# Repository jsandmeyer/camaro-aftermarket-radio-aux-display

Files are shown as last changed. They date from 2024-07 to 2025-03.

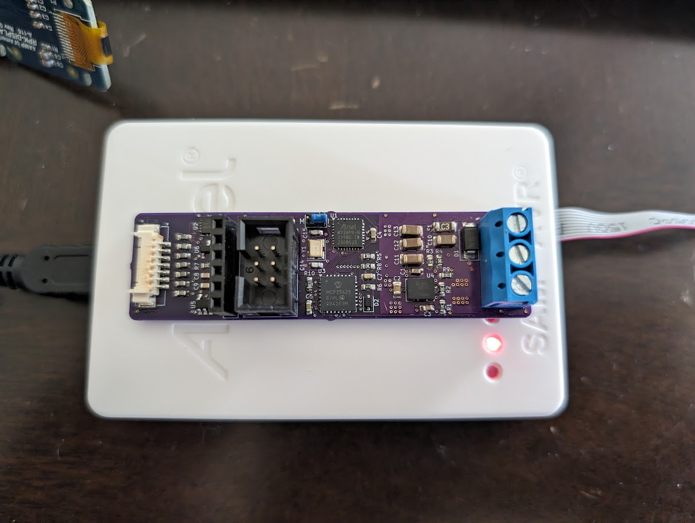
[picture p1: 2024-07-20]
pictures/V3/V3 Soldered and Programmed.jpg

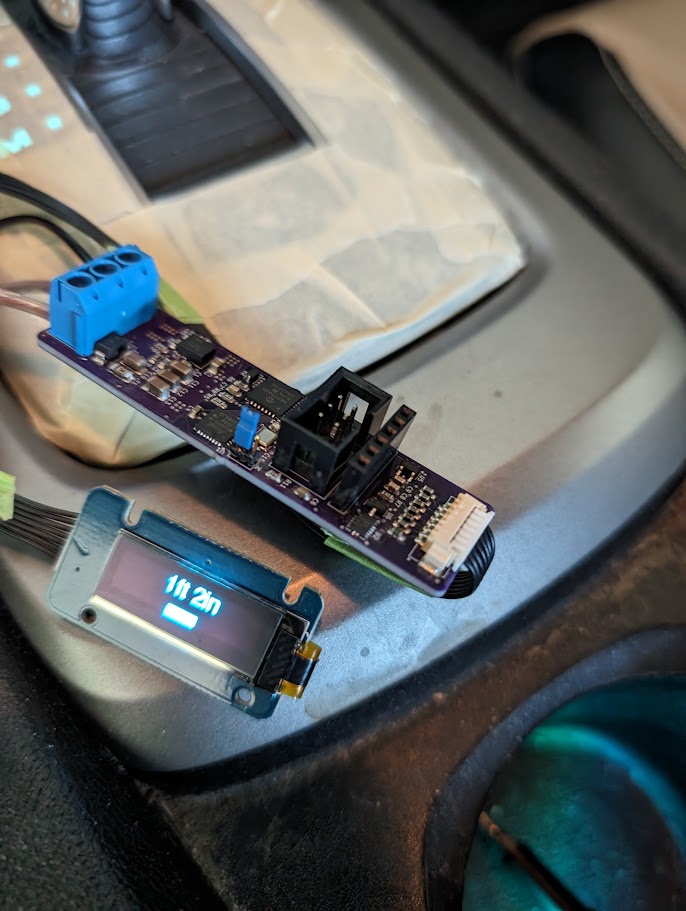
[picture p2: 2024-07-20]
pictures/V3/V3 Reverse Sensor Display.jpg

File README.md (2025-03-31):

## Camaro Temperature & Reverse Sensor Display Shim

This provides resources to help you build something to get the temperature display of a PAC RPK5-GM4102 (or 4101) to function while using a Maestro RR instead of the box that came with the PAC kit.
This is useful if you want to have the Maestro functions to get/update vehicle data, but have the nice function and appearance of the OEM-style HVAC knobs provided by the PAC kit.

### Important
This project is not endorsed by GM, the makers of any trim kits (PAC, iDatalink) or my aftermarket radio, any forum or their users, or anyone else, including any entities named in this repository.
It is a personal project which I have completed, and I have taken a substantial risk to my own property by building and installing this project.

This project (except for PCB footprints supplied by KiCad's included files) is licensed under the MIT license.
Please read the attached LICENSE document.
All code was written by myself, based on documentation provided by libraries or electronic part providers.
All PCB design (except for some footprints) was completed by myself.

### Background

[This forum post on camaro5.com](https://www.camaro5.com/forums/showthread.php?t=588249) goes over the process of combining the two dash kit elements.
Note the OP and others never got the temperature display to work.
This is because the PAC trim component's harness does not have CANBUS access, and the PAC controller was relaying the temperature (and possibly other data) over the Serial line running between the radio and HVAC harnesses.

### Goal

My goal was simply to display the temperature on the OLED.
In the process of design, I also decied to have it show backup sensor data.
The original MyLink radio showed a triangle with an exclamation point in one of five positions over the backup camera when reversing, and it would change color and flash depending on distance.
I wanted to display something similar on the OLED when reversing, because no aftermarket radios seem to support showing the backup sensor data AND camera view at the same time!
The latest version of this module is also able to determine whether the car is displaying metric or imperial units, so there is no need to adjust the jumper on the PCB.

### Reverse Engineering the Hardware

I was able to do some reverse engineering of the PAC RPK5, but without a logic analyzer or serial reading device, I could not do so completely.
I did determine that if I depinned the PAC harness to include only power input, net 5060 low-speed GMLAN, and net 7458 serial data, it would power on and the temperature would display.
However, if I disconnected the TX pin on the PAC controller's internal CANBUS modem (as suggested by its documentation, would force it into "read-only" mode) it would fail completely.
I also discovered that the OLED board used by PAC is a very standard SSD1306 SPI model, and it's roughly equivalent to something you could buy off a hobby site - and the cable connector is also a standard Molex PicoBlade (though the included cable is a crossover cable, likely not made by Molex).

### Reverse Engineering the CANBUS

#### Hardware and Software

I used an Arduino Uno and the [Sparkfun CANBUS shield](https://www.sparkfun.com/products/13262) to prove viability.
With this setup, I was able to snoop on my car's low-speed CANBUS (net 5060) via the main ODB connector using pin 1 for CAN_H and pin 4 for CAN_L and GND.
Using the [mcp_can library](https://github.com/coryjfowler/MCP_CAN_lib) I was able to read temperature and other data.
Eventually, some light googling got me [some details](https://docs.google.com/spreadsheets/d/1pFdixF6W0XK4SR6pXHIlZaFRo9qM5XmAWOK7JcAQdDM/) regarding CANBUS IDs for this car and for other GM cars.

My configuration for this was to:
* Call `CAN0.begin(MCP_STDEXT, CAN_33K3BPS, MCPHZ)` to initialize low-speed CANBUS at 33.3k.
* To configure the filters, I used online resources to try to determine what different ARB IDs meant, and in some cases, even turned off filtering and simply looked through the stream for messages.
* Call `CAN0.setMode(MCP_LISTENONLY)` for read-only CANBUS operation

#### Hardware V2

After confirming this configuration, I switched to using a bare ATMEGA328P chip (similar to the VQFN package I would use in production) and a MCP25625 CAN controller with transciever.
I added ferrite beads to the OLED connector after seeing that PAC decided to use them in their controller board.
I also added a switch to allow selection of Metric vs Imperial units.

#### Hardware V3

This is the first production version.
I added a nice TI power supply designed via Webench, soldered everything down, and also used a jumper to select Metric vs Imperail units (in place of the switch).
Some SMT components are slightly different, like using an AMEGA328PB instead of the ATMEGA328P, or the different footprint of the oscillator.

#### Hardware V6

This is the second production version.
Versions 4 and 5 had issues which prevented them from going to production.
This version includes mounting holes, extra power supply filtering, a watchdog to reboot the MCU if there are too many errors during boot, and auto-sensing of temperature/distance units instead of using a jumper.
The circuit also uses the 3.3V power supply for all logic except for the CAN transciever, which runs on the base 5V.

#### Logs

Temperature was easy.

For my 2014 Camaro, it comes in as 0x10424060 without mask, or 0x212 with the mask.
The second byte `buf[1]` contains the temperature... kind-of.
You have to divide the hex value by two, and subtract 40, to get degrees in celsius.

The backup sensors took more work.

I found that they were streaming data on 0x103A80BB without mask, or 0x1D4 with the mask.

The *second nibble* of the first byte `buf[0] & 0x0F` indicates the park-assist staus.
A value of `0` indicates park-assist is ON, and a value of `F` indicates it is OFF.
The *first nibble* `buf[0] & 0xF0` seems related to something else, and also seemed to vary.

The Bosch parking assist unit seems to report the direction and distance to the *closest* object only.
The second byte `buf[1]` contains the distance, in cm, from 0-255cm.

The position is more complicated.
The Bosch unit has four sensors, but reports three positional channels: Middle, Right, and Left.
It may report a single positional channel, or two adjacent channels, to form five possible locations to render the warning triangle!
The position comes out in bytes 3-4 `buf[2-3]`, split into nibbles indicating positions `[M, R], [N/A, L]`.
A value of 0 indicates the channel is off, but values of 1 thorugh 5 indicate the relative "closeness" and beep/flash speed, with 1 being closest and 5 being furthest.
If two channels are activated, such as to indicate a middle-left obstruction, both channels would have the same value.
I also decided it would be prudent to have a timeout to turn off park-assist display if no data was received, in case the MCU missed the "off" signal.

Lastly, I decided to use data from ARB ID 0x425 to decide whether to use Imperial or Metric units.
The vehicle sends this data multiple times upon startup, so devices using only ACC power (like this) can receive it.

### Assembly

**WARNING: DO THIS ALL AT YOUR OWN RISK.  YOU MAY DAMAGE YOUR CAR OR OTHER EQUIPMENT.  MY DESIGNS PROBABLY HAVE FLAWS; I AM A WEB SOFTWARE ENGINEER AFTER ALL.**

The minimum for this to work is that you need the entire PAC kit, a Maestro RR and its standard cables, and a harness to connect the Maestro RR to the camaro.
For the main harness, you can use the one that comes with the complete iDatalink kit, or just the HRN-HRR-GM2 if you want to re-pin the harness (mandatory).

If you use the harness with the iDatalink trim kit, just leave the HVAC connector and trim connector hanging.
For the cheap option, I originally removed pins 2, 13, 20, and 23 from the HRN-HRR-GM2 to make it seem to work.
If you are particularly clever, you might be able to figure out how to wire in the car's microphone to the harness, like the PAC kit does, and connect it to a 3.5mm jack for the radio.
However, for my final build, I did use the harness included in the KIT-CAM1 with the HVAC control disconnected.

I spliced into the 5060 Low-Speed GMLAN cable, the GND line, and the red "accessory power" line between the Maestro RR unit and my aftermarket radio to power the circuit board.

I used a non-crossover Molex Picoblade cable to connect the circuit board to the OLED display.
I had to temporarily remove a retaining clip from the RPK5 trim to install the cable.
I believe the cable included in the RPK5 is a crossover cable, **please do not use the included display cable for this project**.

See my analysis of the various harness connector configurations in the `2014 camaro connectors.xlsx` file in this repository.

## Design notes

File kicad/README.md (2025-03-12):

### PCB files

PCB construction:

* 4-layer PCB with 5mil trace width and spacing, 10mil drill / 20mil via
* Contact finish must be ENIG due to fine-pitch components
* Use a stencil with solder paste and a hot plate or reflow oven for best results

Installation notes:

* Splice ACC power from the controller-to-radio harness (typically red wire), not direct battery (typically yellow wire).  Otherwise, your battery will drain.
* Splice low-speed GMLAN (green/white) and GND (black) from the main harness.
* Use a NEW 7-pin Molex PicoBlade cable (F-F) to connect.  DO NOT use the crossover cable that came with the trim unless you intend to re-pin the cable.  Wrap the cable in harness tape.
* You will have to remove one of the retention clips on the trim temporarily to replace the cable.
* The new circuit board should be installed in the cavity that the HVAC wires come through, below the radio.

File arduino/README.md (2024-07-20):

### Arduino Sketch

Compiled sketch size is about 28kb.

External libraries needed:

* mcp_can by coryjfowler v1.5.1
* Adafruit GFX Library 1.11.9
* Adafruit SSD1306 2.5.9

Install board variant from this link to %LocalAppData%/Arduino15/packages/arduino/hardware/avr/1.8.6/variants/pb-variant
https://github.com/MCUdude/MiniCore/blob/master/avr/variants/pb-variant/pins_arduino.h

Create a copy of the "uno" board in your boards.txt with a new designator and name, like uno_pb (name Arudino Uno PB mod).
Change the "variant" value of this copy to "pb-variant" to represent the new folder/file.

I programmed with ATMEL Ice, but an AVIRSP MkII should work too.
I used a standard FTDI interface for "debugging" via serial.

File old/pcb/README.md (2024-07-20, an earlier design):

### PCB files

PCB construction:

* 4-layer PCB with 5mil trace width and spacing support, and standard drill limits
* Contact finish must be ENIG fdue to fine-pitch components
* Use a stencil with solder paste and a reflow oven or hot plate for best results, especially due to QFN packages

V3: original design, no mounting holes and no EMI filter.  Boots up about 98% of the time.

V5: new design, but still in progress and untested.  Change notes:

* Added EMI filter based on webench design
* Added mounting holes
* 3.3V power supply replaced with model with more features
* 3.3V power supply will wait for 5V PGOOD signal
* OLED RESET controller removed; reset pin now feeds from MCU
* Level shifter is repalced with a device with more pins
* Level shifter is disabled until 3.3V PGOOD signal

Installation notes:

* Splice ACC power from the brain-to-radio harness (typically red wire), not direct battery (typically yellow wire).  Otherwise, your battery will drain.
* Splice low-speed GMLAN (green/white) and GND (black) from the main harness.
* Use a long, standard Molex PicoBlade cable (F-F) to connect.  Do not use the crossover cable that came with the trim.  Wrap the cable in harness tape.
* You will have to remove one of the tabs on the trim temporarily to replace the cable.
* The new circuit board should be installed in the cavity that the HVAC wires come through, below the radio.

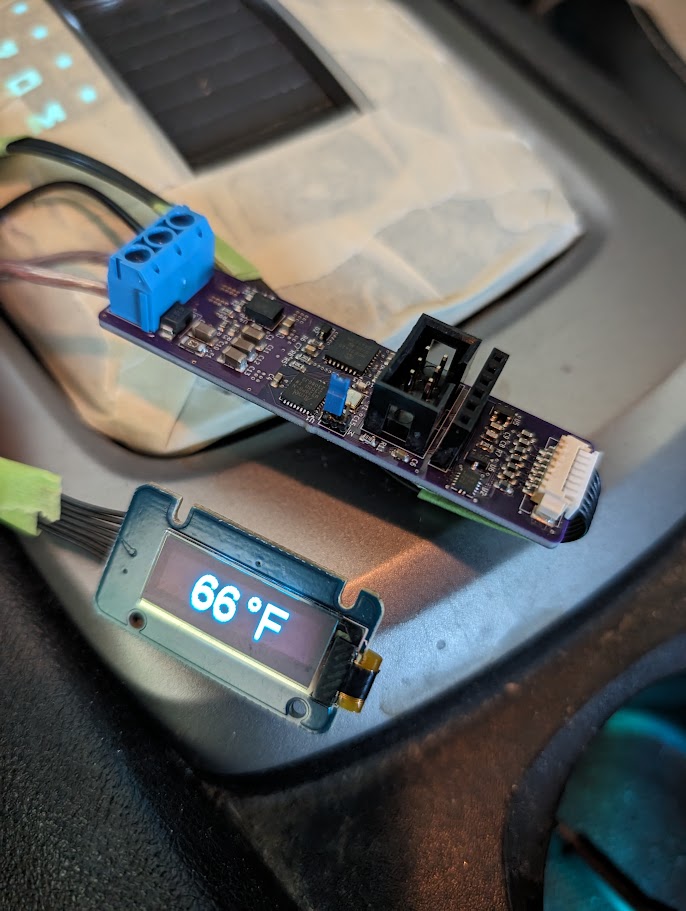
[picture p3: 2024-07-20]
pictures/V3/V3 Temperature Display.jpg

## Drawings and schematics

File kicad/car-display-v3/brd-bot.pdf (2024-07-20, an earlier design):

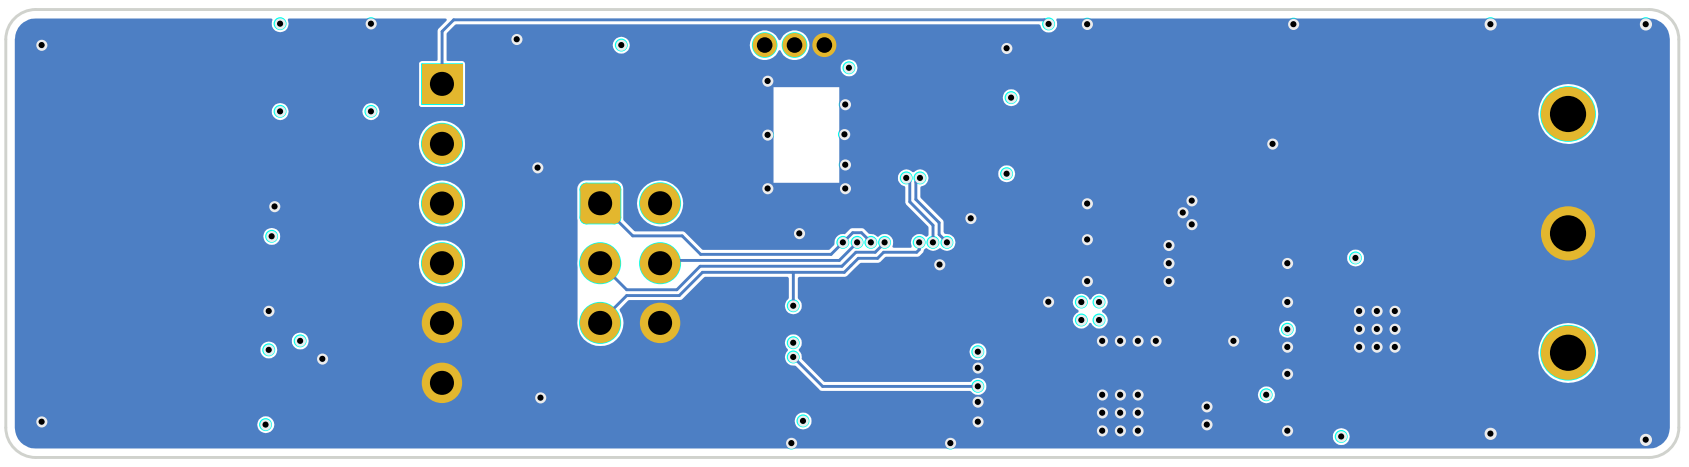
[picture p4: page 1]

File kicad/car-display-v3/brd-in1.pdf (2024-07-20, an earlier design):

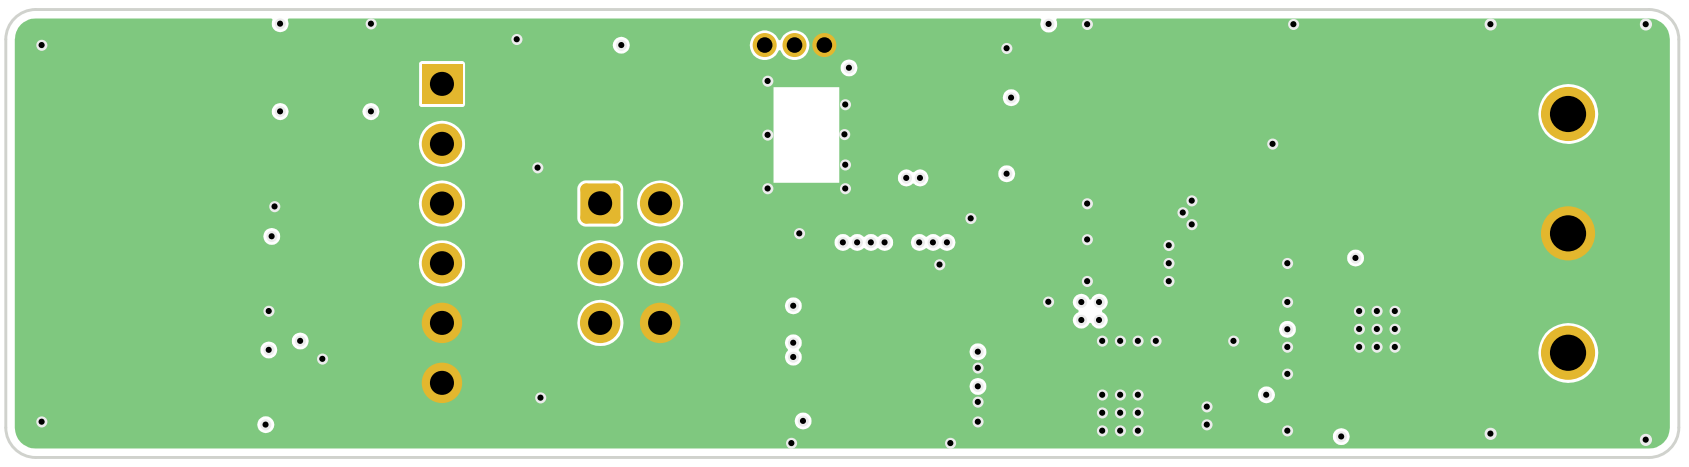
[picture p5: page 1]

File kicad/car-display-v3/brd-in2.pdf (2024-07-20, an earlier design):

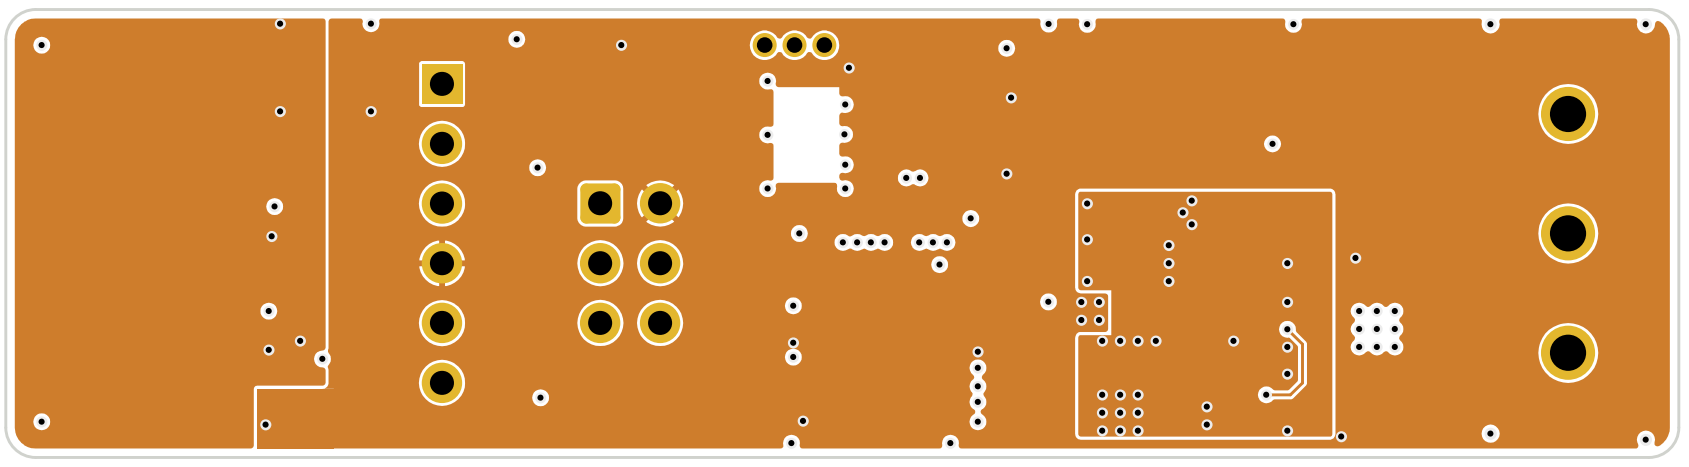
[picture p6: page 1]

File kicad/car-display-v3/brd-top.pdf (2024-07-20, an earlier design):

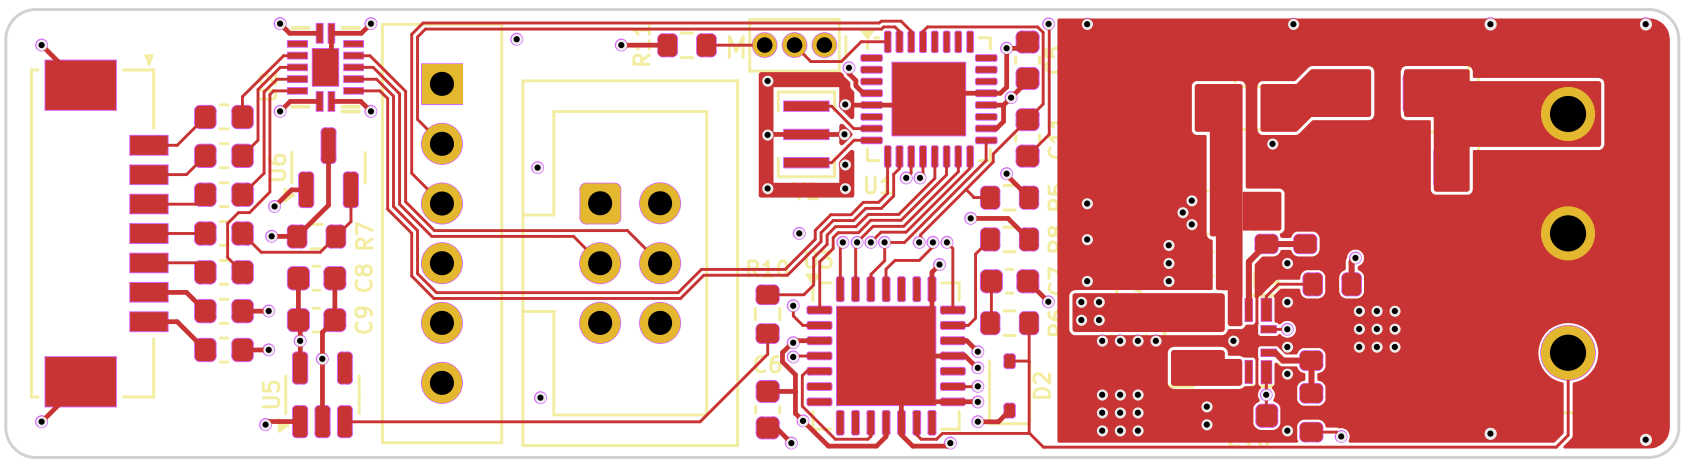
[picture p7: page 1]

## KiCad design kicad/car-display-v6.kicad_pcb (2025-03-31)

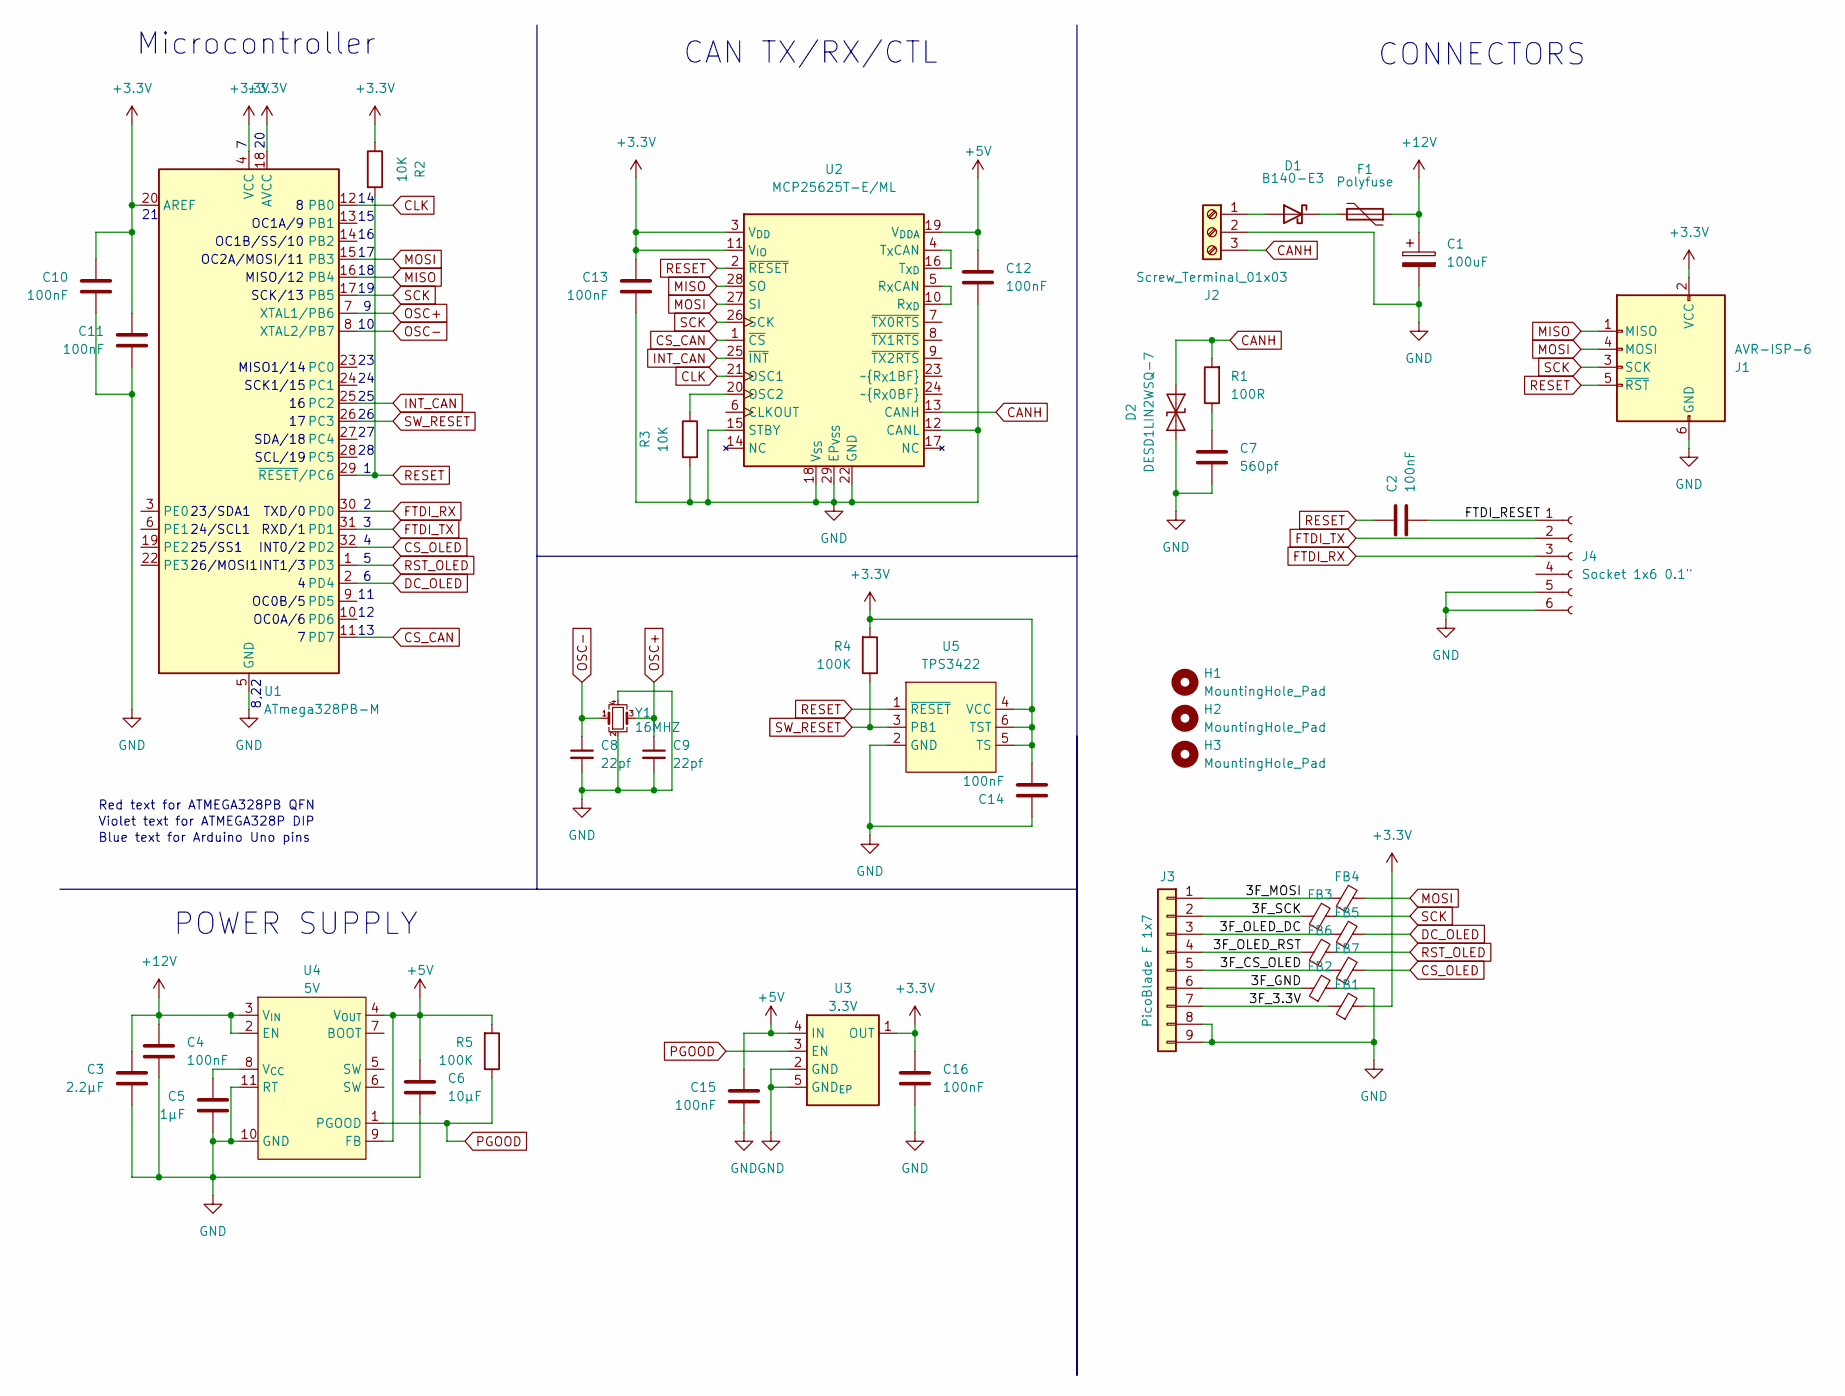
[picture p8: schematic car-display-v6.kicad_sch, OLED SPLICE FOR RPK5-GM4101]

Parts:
C1: 100uF; CP_Elec_6.3x7.7
C2, C4, C10, C11, C12, C13, C14, C15, C16: 100nF; C_0402_1005Metric
C3: 2.2µF; C_0805_2012Metric
C5: 1µF; C_0603_1608Metric
C6: 10µF; C_0805_2012Metric
C7: 560pf; C_0603_1608Metric
C8, C9: 22pf; C_0402_1005Metric
D1: B140-E3; D_SMA
D2: DESD1LIN2WSQ-7; D_SOD-323
F1: Polyfuse; Fuse_1206_3216Metric
FB1, FB2, FB3, FB4, FB5, FB6, FB7: 120X; L_0402_1005Metric
H1, H2, H3: MountingHole_Pad; MountingHole_2.2mm_M2_DIN965
J1: AVR-ISP-6; PinHeader_ISP_POGO
J2: Screw_Terminal_01x03; TerminalBlock_3P
J3: PicoBlade F 1x7; CON_532610771_MOD
J4: Socket 1x6 0.1"; PinSocket_1x06_P2.54mm_Vertical_Box
R1: 100R; R_0603_1608Metric
R2, R3: 10K; R_0402_1005Metric
R4, R5: 100K; R_0402_1005Metric
U1: ATmega328PB-M; QFN-32-1EP_5x5mm_P0.5mm_EP3.1x3.1mm
U2: MCP25625T-E/ML; QFN-28-1EP_6x6mm_P0.65mm_EP4.25x4.25mm
U3: 3.3V; Texas_X2SON-4_1x1mm_P0.65mm_MOD
U4: 5V; QFN-FCMOD_TI_11B
U5: TPS3422; Texas_USON-6_1x1.45mm_P0.5mm_SMD
Y1: 16MHZ; Crystal_SMD_3225-4Pin_3.2x2.5mm

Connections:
+3.3V: C10.1, C11.1, C13.1, C14.2, C16.1, FB1.2, J1.2 (VCC), R2.1, R4.2, U1.4 (VCC), U1.18 (AVCC), U1.20 (AREF), U2.3 (V_{DD}), U2.11 (V_{IO}), U3.1 (OUT), U5.4 (VCC), U5.5 (TS), U5.6 (TST)
+5V: C6.1, C12.1, C15.1, R5.2, U2.19 (V_{DDA}), U3.4 (IN), U4.4 (V_{OUT}), U4.9 (FB)
+12V: C1.1, C3.1, C4.1, F1.1, U4.2 (EN), U4.3 (V_{IN})
/3F_3.3V: FB1.1, J3.7
/3F_CS_OLED: FB7.1, J3.5
/3F_GND: FB2.1, J3.6
/3F_MOSI: FB4.1, J3.1
/3F_OLED_DC: FB5.1, J3.3
/3F_OLED_RST: FB6.1, J3.4
/3F_SCK: FB3.1, J3.2
/FTDI_RESET: C2.2, J4.1
CANH: D2.2 (A2), J2.3, R1.2, U2.13 (CANH)
CLK: U1.12 (PB0), U2.21 (OSC1)
CS_CAN: U1.11 (PD7), U2.1 (~CS)
CS_OLED: FB7.2, U1.32 (PD2)
DC_OLED: FB5.2, U1.2 (PD4)
FTDI_RX: J4.3, U1.30 (PD0)
FTDI_TX: J4.2, U1.31 (PD1)
GND: C1.2, C3.2, C4.2, C5.2, C6.2, C7.2, C8.2, C9.2, C10.2, C11.2, C12.2, C13.2, C14.1, C15.2, C16.2, D2.1 (A1), FB2.2, J1.6 (GND), J2.2, J3.8, J3.9, J4.5, J4.6, R3.2, U1.5 (GND), U1.21 (GND), U1.33 (GND), U2.12 (CANL), U2.15 (STBY), U2.18 (V_{SS}), U2.22 (GND), U2.29 (EP_{VSS}), U3.2 (GND), U3.5 (GND_{EP}), U4.10 (GND), U4.11 (RT), U5.2 (GND), Y1.2, Y1.4
INT_CAN: U1.25 (PC2), U2.25 (~INT)
MISO: J1.1 (MISO), U1.16 (PB4), U2.28 (SO)
MOSI: FB4.2, J1.4 (MOSI), U1.15 (PB3), U2.27 (SI)
unnamed: C7.1, R1.1
unnamed: D1.2 (A), J2.1
unnamed: D1.1 (K), F1.2
unnamed: R3.1, U2.20 (OSC2)
unnamed: U2.5 (R_{X}CAN), U2.10 (R_{XD})
unnamed: U2.4 (T_{X}CAN), U2.16 (T_{XD})
unnamed: C5.1, U4.8 (V_{CC})
OSC+: C9.1, U1.7 (XTAL1/PB6), Y1.3
OSC-: C8.1, U1.8 (XTAL2/PB7), Y1.1
PGOOD: R5.1, U3.3 (EN), U4.1 (PGOOD)
RESET: C2.1, J1.5 (~RST), R2.2, U1.29 (~RESET/PC6), U2.2 (~RESET), U5.1 (~RESET)
RST_OLED: FB6.2, U1.1 (PD3)
SCK: FB3.2, J1.3 (SCK), U1.17 (PB5), U2.26 (SCK)
SW_RESET: R4.1, U1.26 (PC3), U5.3 (PB1)

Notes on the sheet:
23/SDA1
OC0B/5
INT1/3
RXD/1
INT0/2
Red text for ATMEGA328PB QFN
CAN TX/RX/CTL
SCK1/15
8,22
OC1B/SS/10
OC0A/6
POWER SUPPLY
Blue text for Arduino Uno pins
SCL/19
24/SCL1
SCK/13
TXD/0
SDA/18
26/MOSI1
CONNECTORS
MISO/12
OC1A/9
MISO1/14
25/SS1
OC2A/MOSI/11
Microcontroller
Violet text for ATMEGA328P DIP

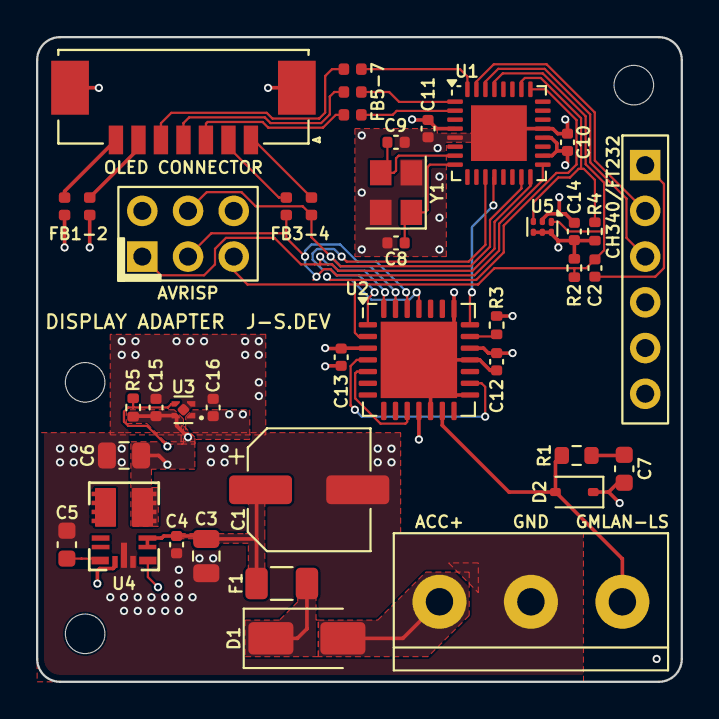
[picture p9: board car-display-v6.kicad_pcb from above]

Board: 4 copper layers, 35.8 x 35.8 mm, 44 parts (0 on the bottom side), 36 nets.

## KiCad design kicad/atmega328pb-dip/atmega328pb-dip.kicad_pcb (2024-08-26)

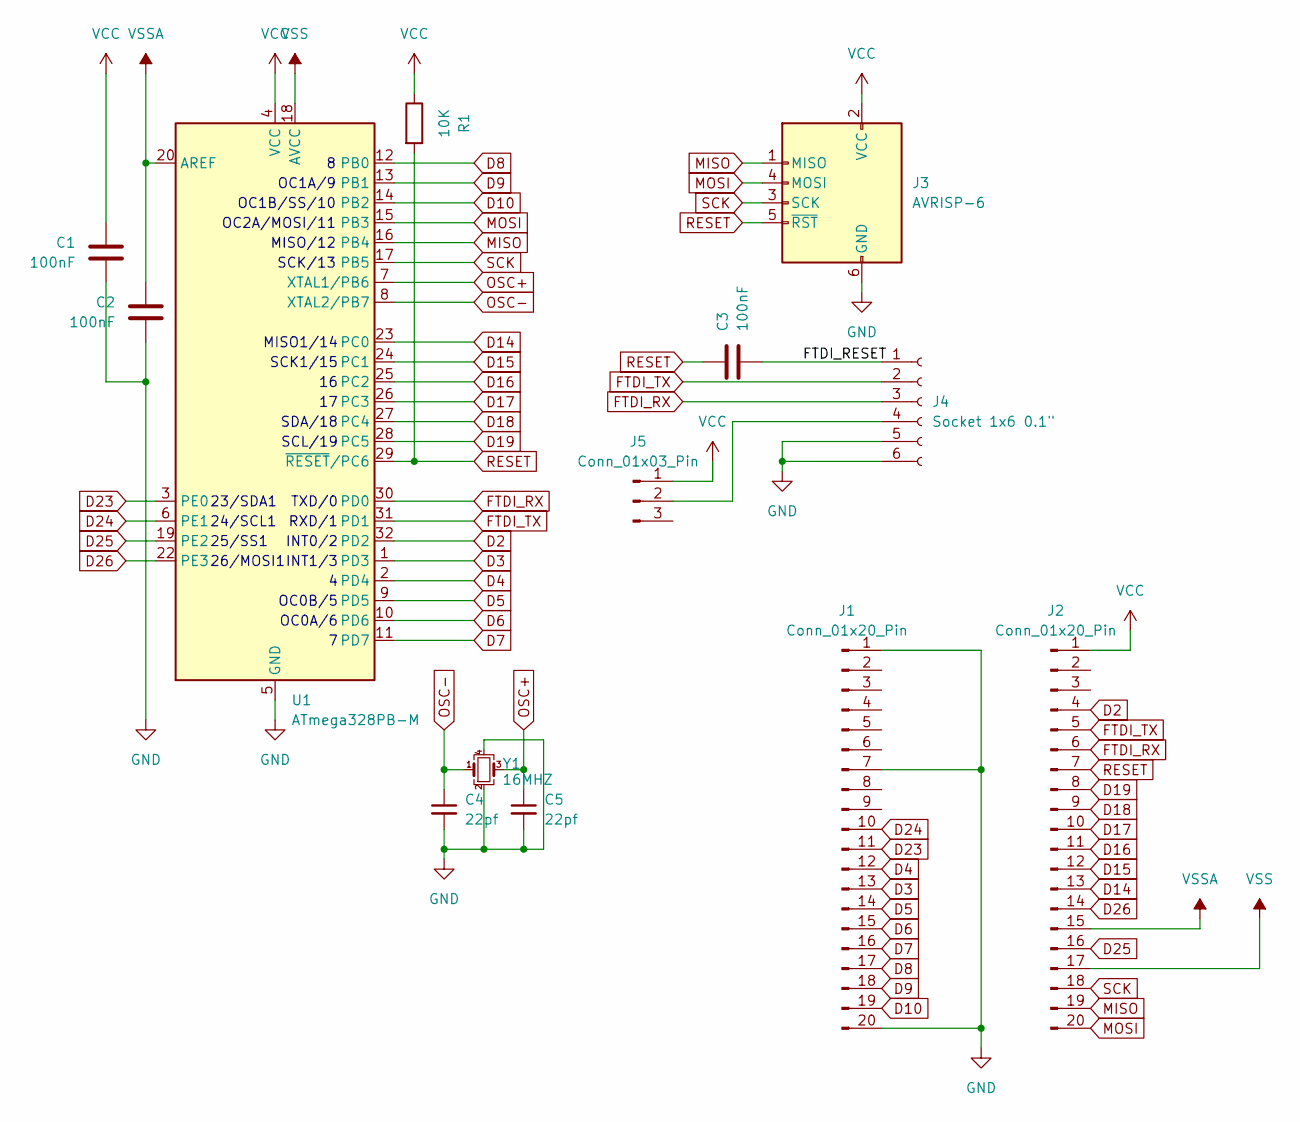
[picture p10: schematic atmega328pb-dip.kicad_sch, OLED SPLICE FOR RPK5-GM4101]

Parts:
C1, C2, C3: 100nF; C_0402_1005Metric
C4, C5: 22pf; C_0402_1005Metric
J1, J2: Conn_01x20_Pin; PinHeader_1x20_P2.54mm_Vertical
J3: AVRISP-6; PinHeader_ISP_POGO
J4: Socket 1x6 0.1"; PinSocket_1x06_P2.54mm_Vertical_Box
J5: Conn_01x03_Pin; PinHeader_1x03_P2.54mm_Vertical
R1: 10K; R_0402_1005Metric
U1: ATmega328PB-M; QFN-32-1EP_5x5mm_P0.5mm_EP3.1x3.1mm
Y1: 16MHZ; Crystal_SMD_3225-4Pin_3.2x2.5mm

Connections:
/FTDI_RESET: C3.2, J4.1
D2: J2.4, U1.32 (PD2)
D3: J1.13, U1.1 (PD3)
D4: J1.12, U1.2 (PD4)
D5: J1.14, U1.9 (PD5)
D6: J1.15, U1.10 (PD6)
D7: J1.16, U1.11 (PD7)
D8: J1.17, U1.12 (PB0)
D9: J1.18, U1.13 (PB1)
D10: J1.19, U1.14 (PB2)
D14: J2.13, U1.23 (PC0)
D15: J2.12, U1.24 (PC1)
D16: J2.11, U1.25 (PC2)
D17: J2.10, U1.26 (PC3)
D18: J2.9, U1.27 (PC4)
D19: J2.8, U1.28 (PC5)
D23: J1.11, U1.3 (PE0)
D24: J1.10, U1.6 (PE1)
D25: J2.16, U1.19 (PE2)
D26: J2.14, U1.22 (PE3)
FTDI_RX: J2.6, J4.3, U1.30 (PD0)
FTDI_TX: J2.5, J4.2, U1.31 (PD1)
GND: C1.2, C2.2, C4.2, C5.2, J1.1, J1.7, J1.20, J3.6 (GND), J4.5, J4.6, U1.5 (GND), U1.21 (GND), U1.33 (GND), Y1.2, Y1.4
MISO: J2.19, J3.1 (MISO), U1.16 (PB4)
MOSI: J2.20, J3.4 (MOSI), U1.15 (PB3)
unnamed: J4.4, J5.2
OSC+: C5.1, U1.7 (XTAL1/PB6), Y1.3
OSC-: C4.1, U1.8 (XTAL2/PB7), Y1.1
RESET: C3.1, J2.7, J3.5 (~RST), R1.2, U1.29 (~RESET/PC6)
SCK: J2.18, J3.3 (SCK), U1.17 (PB5)
VCC: C1.1, J2.1, J3.2 (VCC), J5.1, R1.1, U1.4 (VCC)
VSS: J2.17, U1.18 (AVCC)
VSSA: C2.1, J2.15, U1.20 (AREF)

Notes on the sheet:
23/SDA1
OC0B/5
INT1/3
RXD/1
INT0/2
SCK1/15
OC1B/SS/10
OC0A/6
SCL/19
24/SCL1
SCK/13
TXD/0
SDA/18
26/MOSI1
MISO/12
OC1A/9
MISO1/14
25/SS1
OC2A/MOSI/11

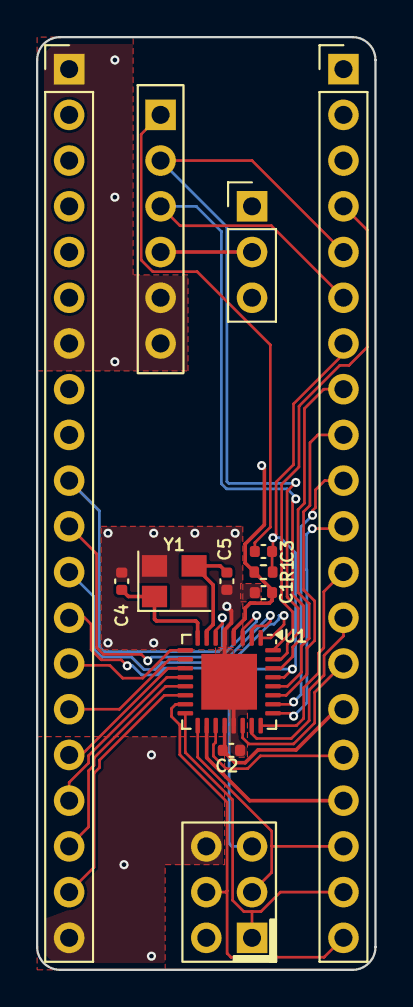
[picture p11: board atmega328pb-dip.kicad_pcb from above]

Board: 2 copper layers, 18.8 x 51.8 mm, 13 parts (0 on the bottom side), 33 nets.

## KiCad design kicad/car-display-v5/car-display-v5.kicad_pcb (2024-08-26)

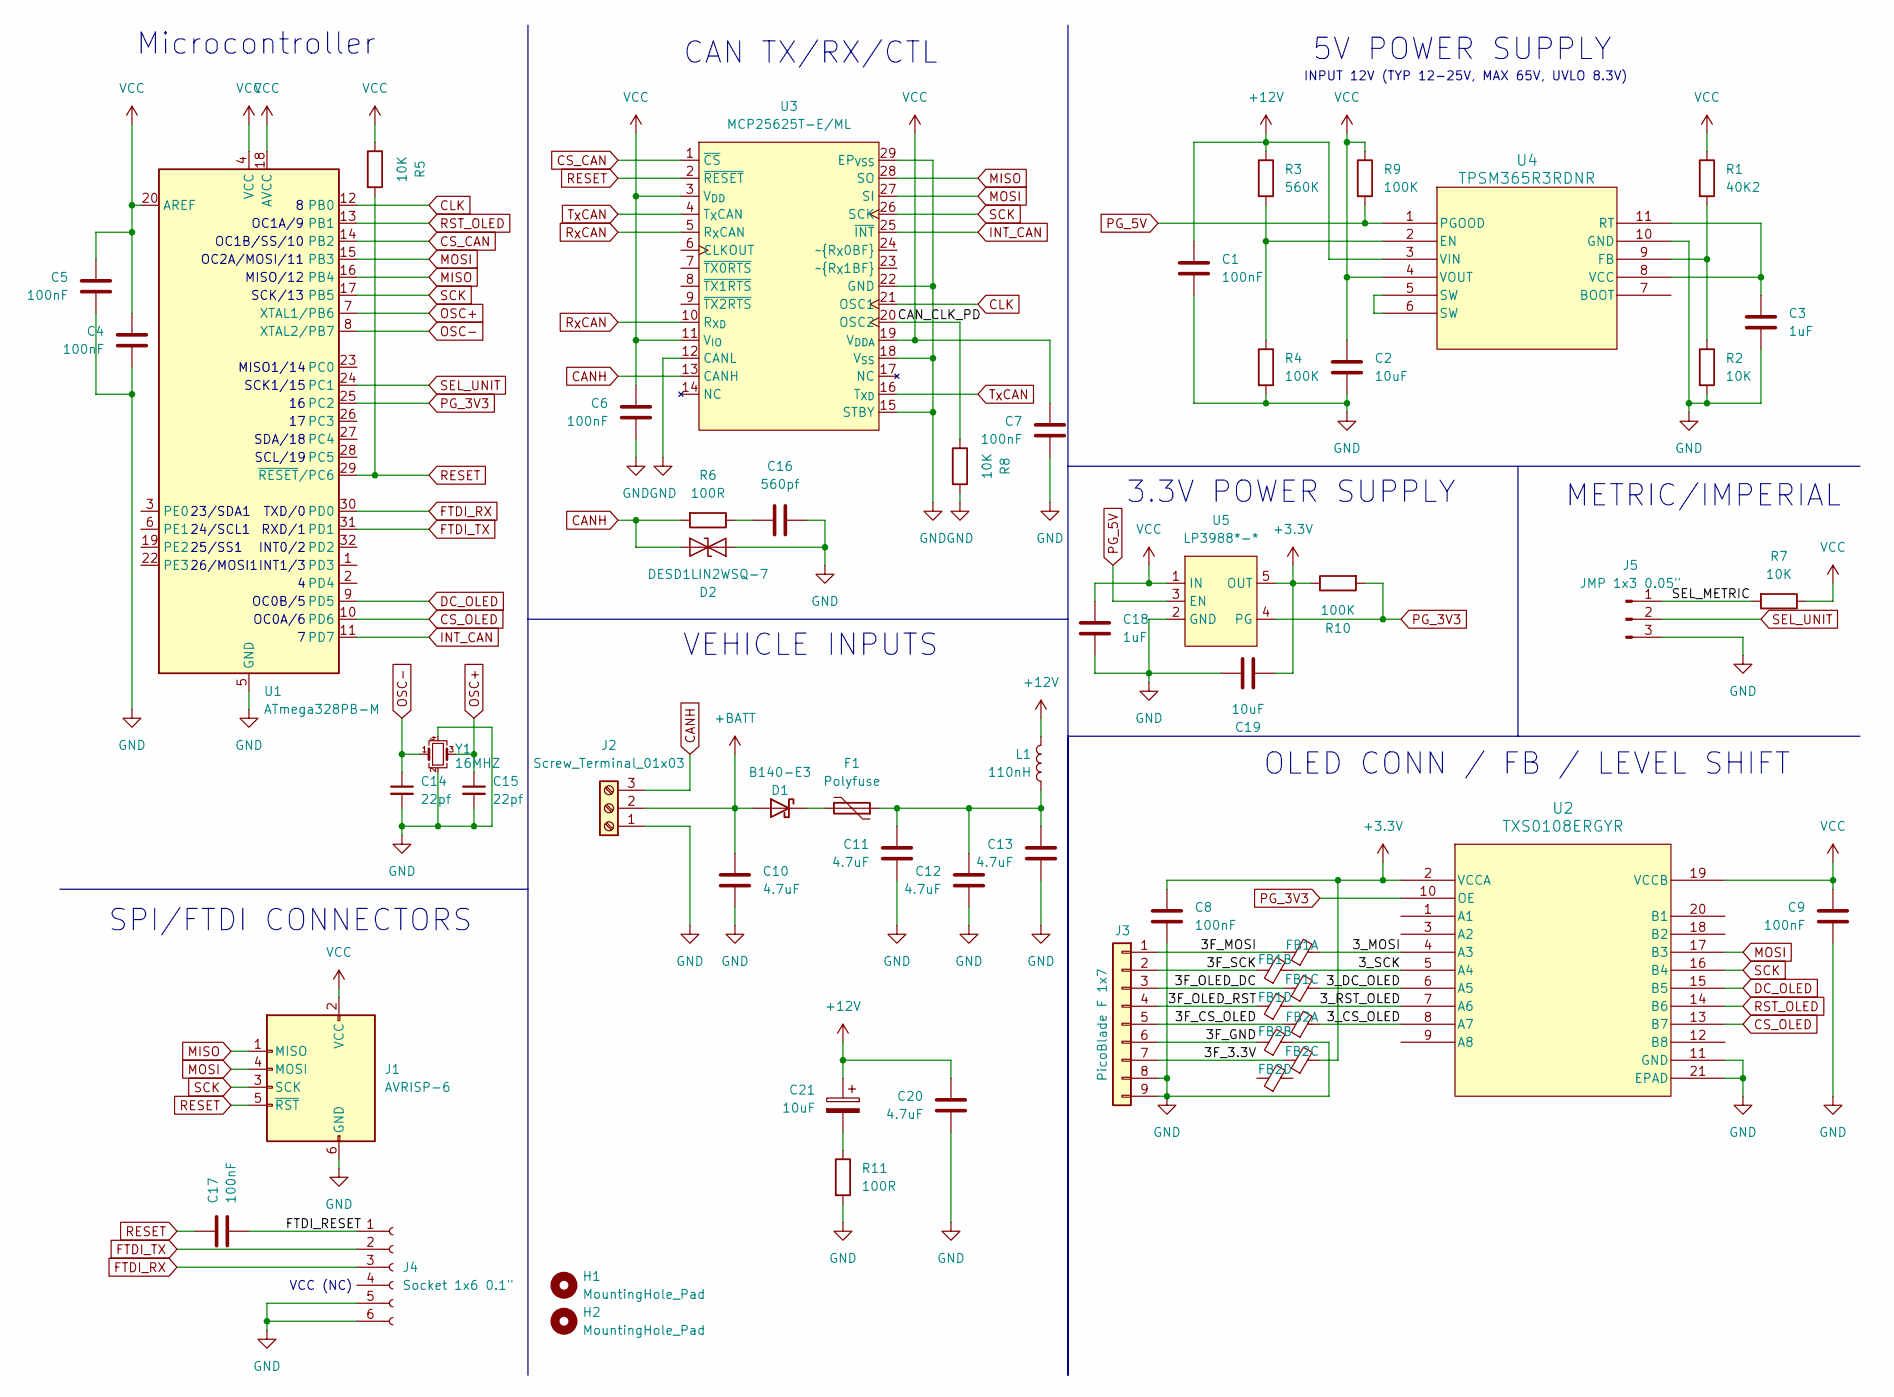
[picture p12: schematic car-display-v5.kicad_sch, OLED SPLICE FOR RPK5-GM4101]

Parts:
C1: 100nF; C_0603_1608Metric
C2: 10uF; C_0805_2012Metric
C3, C18: 1uF; C_0603_1608Metric
C4, C5, C6, C7, C8, C9, C17: 100nF; C_0402_1005Metric
C10, C11, C12, C13, C20: 4.7uF; C_1206_3216Metric
C14, C15: 22pf; C_0402_1005Metric
C16: 560pf; C_0603_1608Metric
C19: 10uF; C_0603_1608Metric
C21: 10uF; CP_Elec_5x5.9
D1: B140-E3; D_SMA
D2: DESD1LIN2WSQ-7; D_SOD-323
F1: Polyfuse; Fuse_1206_3216Metric
FB1, FB2: FerriteBead_Small_Array; fb_array_0805
H1, H2: MountingHole_Pad; MountingHole_2.2mm_M2_DIN965
J1: AVRISP-6; PinHeader_ISP_POGO
J2: Screw_Terminal_01x03; TerminalBlock_bornier-3_P5.08mm
J3: PicoBlade F 1x7; CON_532610771_MOD
J4: Socket 1x6 0.1"; PinSocket_1x06_P2.54mm_Vertical_Box
J5: JMP 1x3 0.05"; PinHeader_1x03_P1.27mm_Vertical_mod
L1: 110nH; L_0603_1608Metric
R1: 40K2; R_0402_1005Metric
R2, R5, R7, R8: 10K; R_0402_1005Metric
R3: 560K; R_0402_1005Metric
R4, R9, R10: 100K; R_0402_1005Metric
R6, R11: 100R; R_0603_1608Metric
U1: ATmega328PB-M; QFN-32-1EP_5x5mm_P0.5mm_EP3.1x3.1mm
U2: TXS0108ERGYR; RGY20_3P05X2P05
U3: MCP25625T-E/ML; QFN-28-1EP_6x6mm_P0.65mm_EP4.25x4.25mm_mod1
U4: TPSM365R3RDNR; QFN-FCMOD_365R6FRDN_TEX_M2
U5: LP3988*-*; SOT-23-5
Y1: 16MHZ; Crystal_SMD_3225-4Pin_3.2x2.5mm

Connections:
+3.3V: C8.1, C19.1, FB2.6, R10.1, U2.2 (VCCA), U5.5 (OUT)
+12V: C1.1, C20.1, C21.1, L1.1, R3.1, U4.3 (VIN)
+BATT: C10.1, D1.2 (A), J2.2
/3F_3.3V: FB2.3, J3.7
/3F_CS_OLED: FB2.1, J3.5
/3F_GND: FB2.2, J3.6
/3F_MOSI: FB1.1, J3.1
/3F_OLED_DC: FB1.3, J3.3
/3F_OLED_RST: FB1.4, J3.4
/3F_SCK: FB1.2, J3.2
/3_CS_OLED: FB2.8, U2.8 (A7)
/3_DC_OLED: FB1.6, U2.6 (A5)
/3_MOSI: FB1.8, U2.4 (A3)
/3_RST_OLED: FB1.5, U2.7 (A6)
/3_SCK: FB1.7, U2.5 (A4)
/CAN_CLK_PD: R8.1, U3.20 (OSC2)
/FTDI_RESET: C17.2, J4.1
/SEL_METRIC: J5.1, R7.2
CANH: D2.2 (A2), J2.3, R6.2, U3.13 (CANH)
CLK: U1.12 (PB0), U3.21 (OSC1)
CS_CAN: U1.14 (PB2), U3.1 (~CS)
CS_OLED: U1.10 (PD6), U2.13 (B7)
DC_OLED: U1.9 (PD5), U2.15 (B5)
FTDI_RX: J4.3, U1.30 (PD0)
FTDI_TX: J4.2, U1.31 (PD1)
GND: C1.2, C2.2, C3.2, C4.2, C5.2, C6.2, C7.2, C8.2, C9.2, C10.2, C11.2, C12.2, C13.2, C14.2, C15.2, C16.2, C18.2, C19.2, C20.2, D2.1 (A1), FB2.7, J1.6 (GND), J2.1, J3.8, J3.9, J4.5, J4.6, J5.3, R2.2, R4.2, R8.2, R11.2, U1.5 (GND), U1.21 (GND), U1.33 (GND), U2.11 (GND), U2.21 (EPAD), U3.12 (CANL), U3.15 (STBY), U3.18 (V_{SS}), U3.22 (GND), U3.29 (EP_{VSS}), U4.10 (GND), U5.2 (GND), Y1.2, Y1.4
INT_CAN: U1.11 (PD7), U3.25 (~INT)
MISO: J1.1 (MISO), U1.16 (PB4), U3.28 (SO)
MOSI: J1.4 (MOSI), U1.15 (PB3), U2.17 (B3), U3.27 (SI)
unnamed: C11.1, C12.1, C13.1, F1.1, L1.2
unnamed: C16.1, R6.1
unnamed: C21.2, R11.1
unnamed: D1.1 (K), F1.2
unnamed: R3.2, R4.1, U4.2 (EN)
unnamed: R1.2, R2.1, U4.9 (FB)
unnamed: C3.1, U4.8 (VCC), U4.11 (RT)
unnamed: U4.5 (SW), U4.6 (SW)
OSC+: C15.1, U1.7 (XTAL1/PB6), Y1.3
OSC-: C14.1, U1.8 (XTAL2/PB7), Y1.1
PG_3V3: R10.2, U1.25 (PC2), U2.10 (OE), U5.4 (PG)
PG_5V: R9.2, U4.1 (PGOOD), U5.3 (EN)
RESET: C17.1, J1.5 (~RST), R5.2, U1.29 (~RESET/PC6), U3.2 (~RESET)
RST_OLED: U1.13 (PB1), U2.14 (B6)
R_{X}CAN: U3.5 (R_{X}CAN), U3.10 (R_{XD})
SCK: J1.3 (SCK), U1.17 (PB5), U2.16 (B4), U3.26 (SCK)
SEL_UNIT: J5.2, U1.24 (PC1)
T_{X}CAN: U3.4 (T_{X}CAN), U3.16 (T_{XD})
VCC: C2.1, C4.1, C5.1, C6.1, C7.1, C9.1, C18.1, J1.2 (VCC), R1.1, R5.1, R7.1, R9.1, U1.4 (VCC), U1.18 (AVCC), U1.20 (AREF), U2.19 (VCCB), U3.3 (V_{DD}), U3.11 (V_{IO}), U3.19 (V_{DDA}), U4.4 (VOUT), U5.1 (IN)

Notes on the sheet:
23/SDA1
OC0B/5
INT1/3
RXD/1
INT0/2
3.3V POWER SUPPLY
CAN TX/RX/CTL
VEHICLE INPUTS
SCK1/15
OC1B/SS/10
OC0A/6
VCC (NC)
5V POWER SUPPLY
INPUT 12V (TYP 12-25V, MAX 65V, UVLO 8.3V)
SCL/19
24/SCL1
SCK/13
TXD/0
SDA/18
26/MOSI1
SPI/FTDI CONNECTORS
MISO/12
OC1A/9
MISO1/14
25/SS1
OC2A/MOSI/11
OLED CONN / FB / LEVEL SHIFT
Microcontroller
METRIC/IMPERIAL

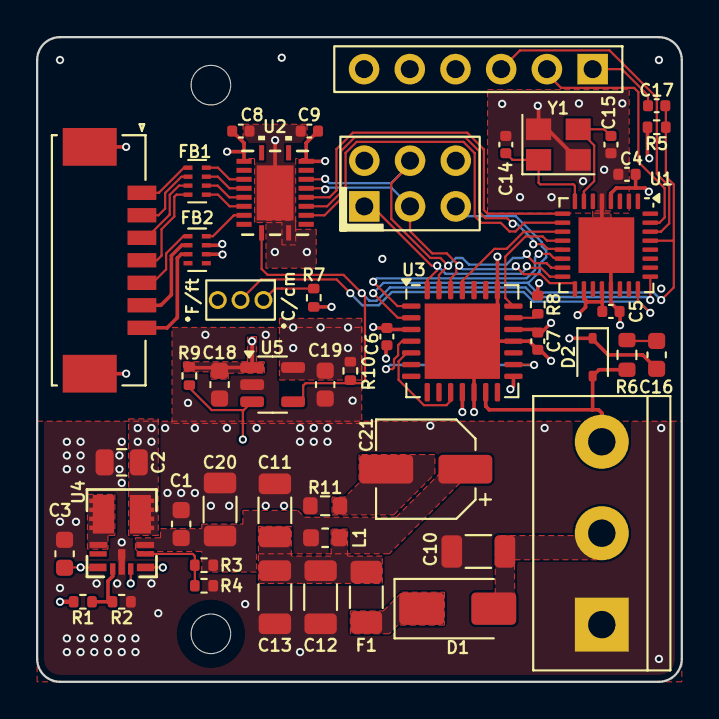
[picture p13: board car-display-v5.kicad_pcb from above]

Board: 4 copper layers, 35.8 x 35.8 mm, 51 parts (0 on the bottom side), 48 nets.

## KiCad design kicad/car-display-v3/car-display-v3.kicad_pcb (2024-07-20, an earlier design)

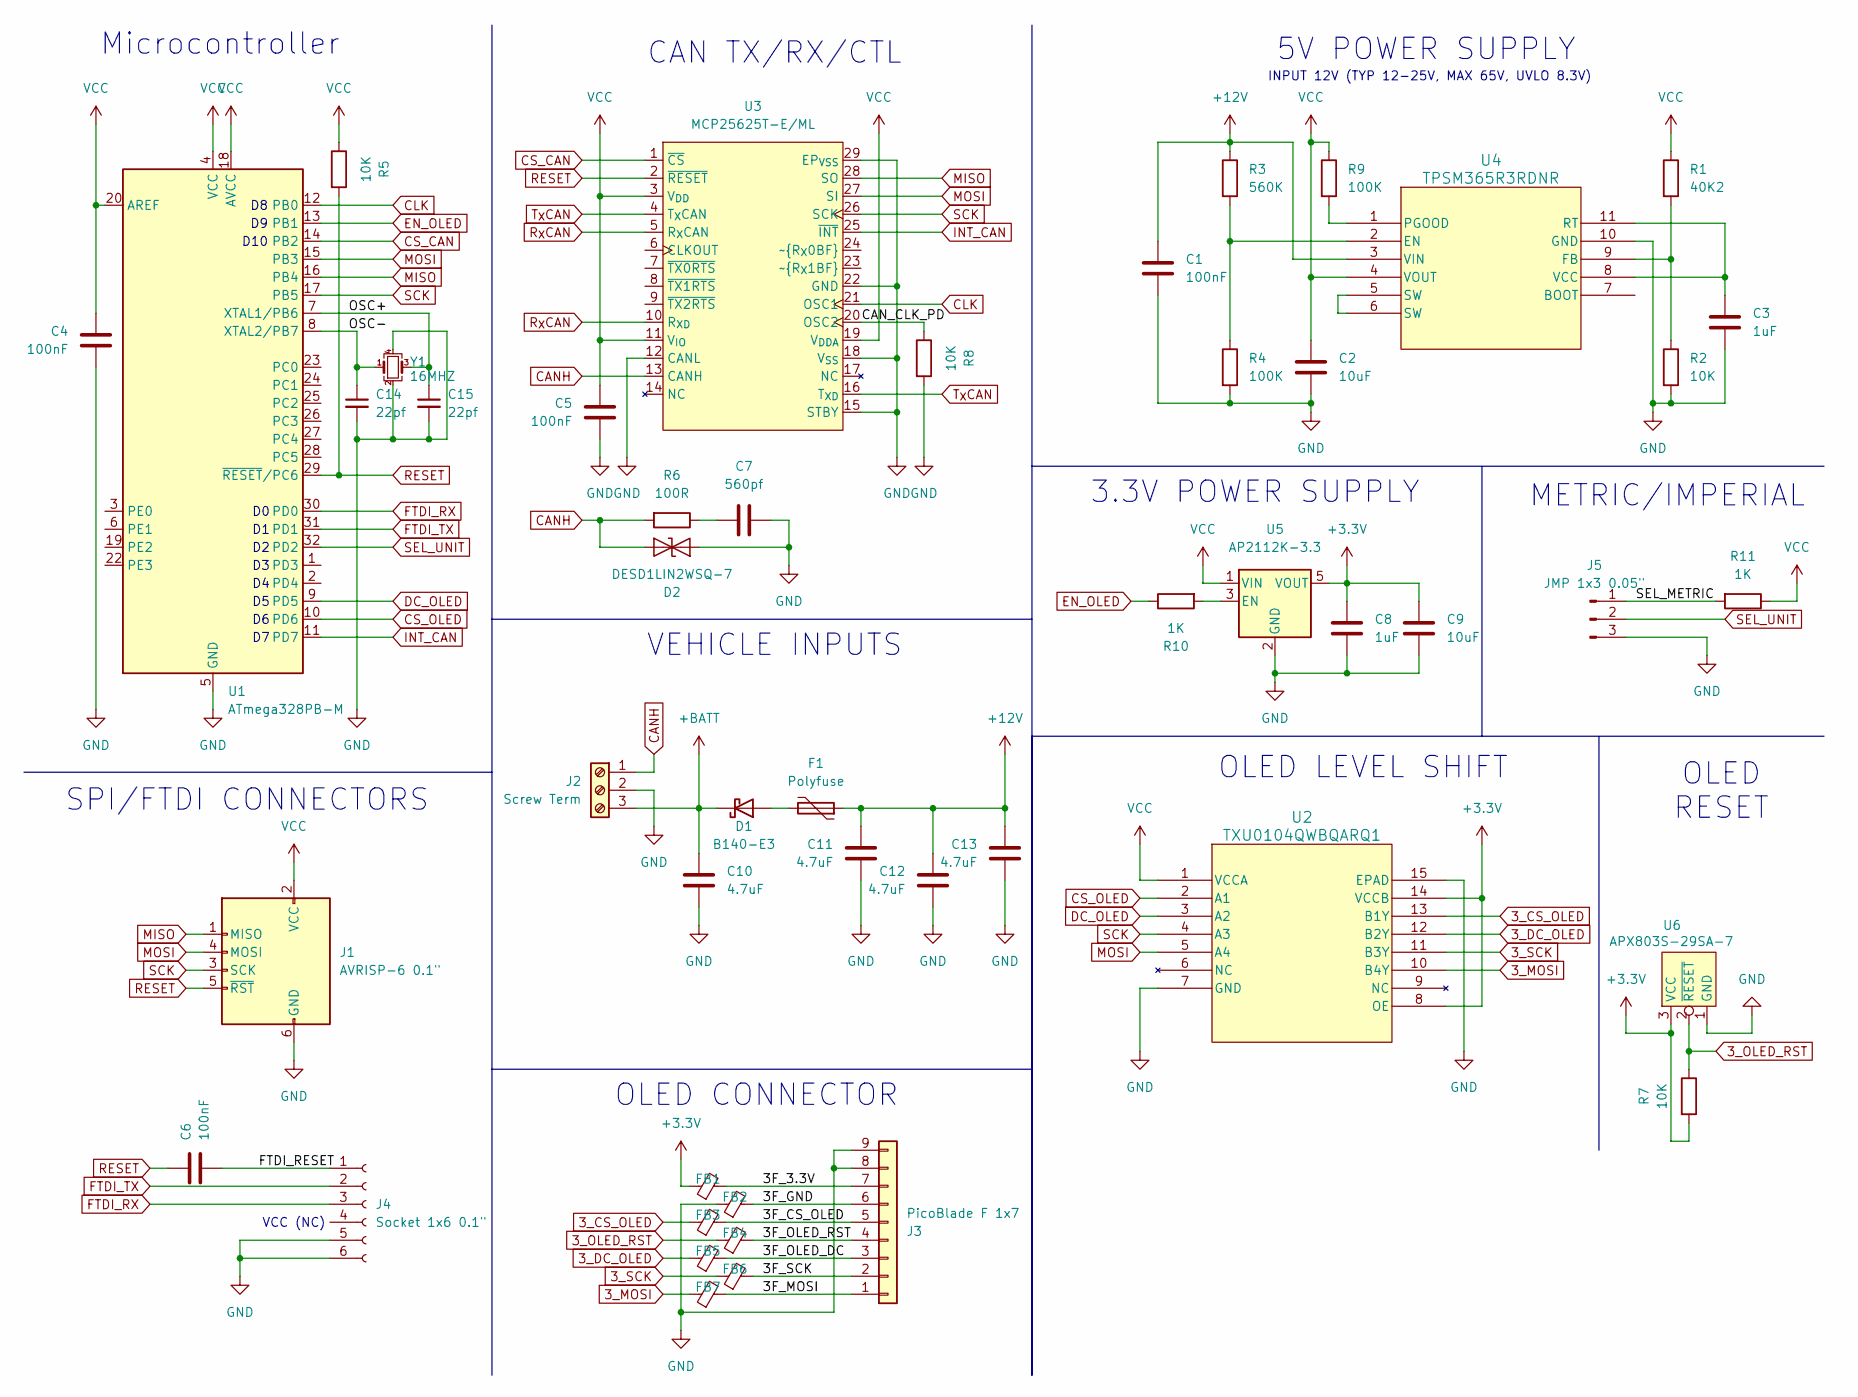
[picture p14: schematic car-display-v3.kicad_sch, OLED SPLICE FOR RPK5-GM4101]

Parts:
C1, C4, C5, C6: 100nF; C_0603_1608Metric
C2: 10uF; C_0805_2012Metric
C3, C8: 1uF; C_0603_1608Metric
C7: 560pf; C_0603_1608Metric
C9: 10uF; C_0603_1608Metric
C10, C11, C12, C13: 4.7uF; C_1206_3216Metric
C14, C15: 22pf; C_0603_1608Metric
D1: B140-E3; D_SMA
D2: DESD1LIN2WSQ-7; D_SOD-323
F1: Polyfuse; Fuse_1206_3216Metric
FB1, FB2, FB3, FB4, FB5, FB6, FB7: MMZ1608S121ATD25; L_0603_1608Metric
J1: AVRISP-6 0.1"; IDC-Header_2x03_P2.54mm_Vertical_mod
J2: Screw Term; screw_term_3
J3: PicoBlade F 1x7; CON_532610771_MOD
J4: Socket 1x6 0.1"; PinSocket_1x06_P2.54mm_Vertical_Box
J5: JMP 1x3 0.05"; PinHeader_1x03_P1.27mm_Vertical_mod
R1: 40K2; R_0603_1608Metric
R2, R5, R7, R8: 10K; R_0603_1608Metric
R3: 560K; R_0603_1608Metric
R4, R9: 100K; R_0603_1608Metric
R6: 100R; R_0603_1608Metric
R10, R11: 1K; R_0603_1608Metric
U1: ATmega328PB-M; QFN-32-1EP_5x5mm_P0.5mm_EP3.1x3.1mm
U2: TXU0104QWBQARQ1; WQFN14_BQA_TEX
U3: MCP25625T-E/ML; QFN-28-1EP_6x6mm_P0.65mm_EP4.25x4.25mm_mod1
U4: TPSM365R3RDNR; QFN-FCMOD_365R6FRDN_TEX_M2
U5: AP2112K-3.3; SOT-23-5
U6: APX803S-29SA-7; SOT-23
Y1: 16MHZ; Crystal_SMD_3225-4Pin_3.2x2.5mm

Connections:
3_CS_OLED: FB3.1, U2.13 (B1Y)
3_DC_OLED: FB5.1, U2.12 (B2Y)
3_MOSI: FB7.1, U2.10 (B4Y)
3_OLED_RST: FB4.1, R7.1, U6.2 (~RESET)
3_SCK: FB6.1, U2.11 (B3Y)
+3.3V: C8.1, C9.1, FB1.1, R7.2, U2.8 (OE), U2.14 (VCCB), U5.5 (VOUT), U6.3 (VCC)
+12V: C1.1, C11.1, C12.1, C13.1, F1.1, R3.1, U4.3 (VIN)
+BATT: C10.1, D1.1 (K), J2.3
/3F_3.3V: FB1.2, J3.7
/3F_CS_OLED: FB3.2, J3.5
/3F_GND: FB2.2, J3.6
/3F_MOSI: FB7.2, J3.1
/3F_OLED_DC: FB5.2, J3.3
/3F_OLED_RST: FB4.2, J3.4
/3F_SCK: FB6.2, J3.2
/CAN_CLK_PD: R8.1, U3.20 (OSC2)
/FTDI_RESET: C6.2, J4.1
/OSC+: C15.1, U1.7 (XTAL1/PB6), Y1.3
/OSC-: C14.1, U1.8 (XTAL2/PB7), Y1.1
/SEL_METRIC: J5.1, R11.2
CANH: D2.2 (A2), J2.1, R6.2, U3.13 (CANH)
CLK: U1.12 (PB0), U3.21 (OSC1)
CS_CAN: U1.14 (PB2), U3.1 (~CS)
CS_OLED: U1.10 (PD6), U2.2 (A1)
DC_OLED: U1.9 (PD5), U2.3 (A2)
EN_OLED: R10.1, U1.13 (PB1)
FTDI_RX: J4.3, U1.30 (PD0)
FTDI_TX: J4.2, U1.31 (PD1)
GND: C1.2, C2.2, C3.2, C4.2, C5.2, C7.2, C8.2, C9.2, C10.2, C11.2, C12.2, C13.2, C14.2, C15.2, D2.1 (A1), FB2.1, J1.6 (GND), J2.2, J3.8, J3.9, J4.5, J4.6, J5.3, R2.2, R4.2, R8.2, U1.5 (GND), U1.21 (GND), U1.33 (GND), U2.7 (GND), U2.15 (EPAD), U3.12 (CANL), U3.15 (STBY), U3.18 (V_{SS}), U3.22 (GND), U3.29 (EP_{VSS}), U4.10 (GND), U5.2 (GND), U6.1 (GND), Y1.2, Y1.4
INT_CAN: U1.11 (PD7), U3.25 (~INT)
MISO: J1.1 (MISO), U1.16 (PB4), U3.28 (SO)
MOSI: J1.4 (MOSI), U1.15 (PB3), U2.5 (A4), U3.27 (SI)
unnamed: C7.1, R6.1
unnamed: D1.2 (A), F1.2
unnamed: R3.2, R4.1, U4.2 (EN)
unnamed: R1.2, R2.1, U4.9 (FB)
unnamed: R9.2, U4.1 (PGOOD)
unnamed: C3.1, U4.8 (VCC), U4.11 (RT)
unnamed: U4.5 (SW), U4.6 (SW)
unnamed: R10.2, U5.3 (EN)
RESET: C6.1, J1.5 (~RST), R5.2, U1.29 (~RESET/PC6), U3.2 (~RESET)
R_{X}CAN: U3.5 (R_{X}CAN), U3.10 (R_{XD})
SCK: J1.3 (SCK), U1.17 (PB5), U2.4 (A3), U3.26 (SCK)
SEL_UNIT: J5.2, U1.32 (PD2)
T_{X}CAN: U3.4 (T_{X}CAN), U3.16 (T_{XD})
VCC: C2.1, C4.1, C5.1, J1.2 (VCC), R1.1, R5.1, R9.1, R11.1, U1.4 (VCC), U1.18 (AVCC), U1.20 (AREF), U2.1 (VCCA), U3.3 (V_{DD}), U3.11 (V_{IO}), U3.19 (V_{DDA}), U4.4 (VOUT), U5.1 (VIN)

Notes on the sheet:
3.3V POWER SUPPLY
CAN TX/RX/CTL
VEHICLE INPUTS
D10
OLED CONNECTOR
VCC (NC)
5V POWER SUPPLY
INPUT 12V (TYP 12-25V, MAX 65V, UVLO 8.3V)
OLED RESET
SPI/FTDI CONNECTORS
OLED LEVEL SHIFT
Microcontroller
METRIC/IMPERIAL

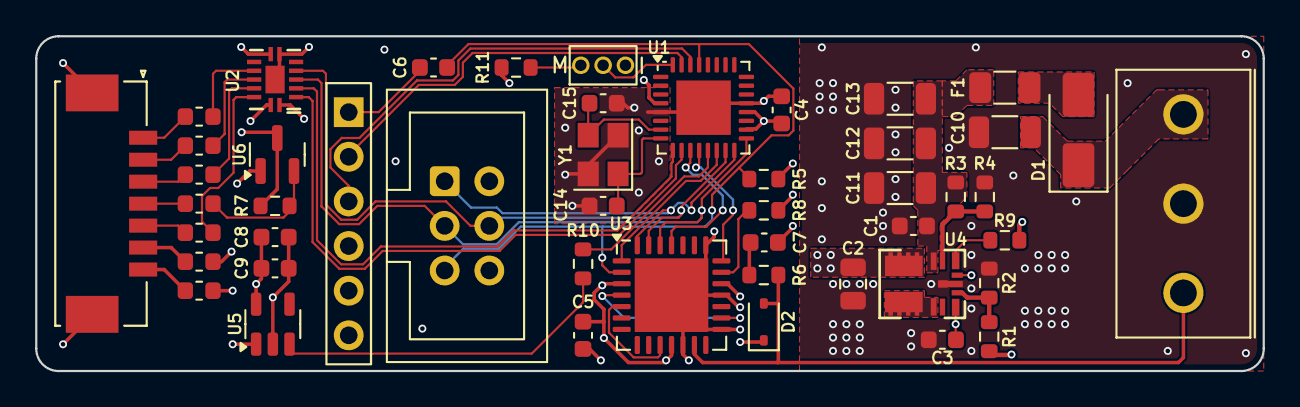
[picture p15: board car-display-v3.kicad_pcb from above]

Board: 4 copper layers, 69.8 x 19.0 mm, 48 parts (0 on the bottom side), 46 nets.

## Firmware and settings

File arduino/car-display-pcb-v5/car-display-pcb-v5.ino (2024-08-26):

#define F_CPU 16000000L
#define MCPHZ MCP_16MHZ
#define SER_BAUD 115200
#define OLED_SPI_BAUD 1000000UL

#include <math.h>
#include <SPI.h>
#include <mcp_can.h>
#include <Adafruit_GFX.h>
#include <Adafruit_SSD1306.h>
#include <Fonts/FreeSans18pt7b.h>
#include <Fonts/FreeSans9pt7b.h>

#define GMLAN_PRI_MASK 0x1C000000
#define GMLAN_PRI_SHIFT 0x1A
#define GMLAN_ARB_MASK 0x03FFE000
#define GMLAN_ARB_SHIFT 0x0D
#define GMLAN_SENDER_MASK 0x00001FFF
#define GMLAN_SENDER_SHIFT 0x00

#define GMLAN_MS(v, m, s) ((v & m) >> s)
#define GMLAN_PRI(v) GMLAN_MS(v, GMLAN_PRI_MASK, GMLAN_PRI_SHIFT)
#define GMLAN_ARB(v) GMLAN_MS(v, GMLAN_ARB_MASK, GMLAN_ARB_SHIFT)
#define GMLAN_SENDER(v) GMLAN_MS(v, GMLAN_SENDER_MASK, GMLAN_SENDER_SHIFT)

#define CAN0_INT 7
#define OLED_DC 5
#define OLED_RST 9
#define UNIT_SW 15
#define SPI_CS_PIN_CAN 10
#define SPI_CS_PIN_OLED 6

#define SPI_MOSI 11
#define SPI_MISO 12
#define SPI_SCK 13

#define PGOOD_3V3 16

#define SCREEN_WIDTH 128 // OLED display width, in pixels
#define SCREEN_HEIGHT 32 // OLED display height, in pixels

#define PA_BAR_H 8
#define PA_BAR_MARGIN_TOTAL (SCREEN_WIDTH % 5)
#define PA_BAR_MARGIN (PA_BAR_MARGIN_TOTAL / 2)
#define PA_BAR_W (SCREEN_WIDTH / 5)
#define PA_BAR_EXTRA_W (PA_BAR_MARGIN_TOTAL % 2)
#define PA_TIMEOUT 10000UL

// Adafruit_SSD1306 display(SCREEN_WIDTH, SCREEN_HEIGHT, SPI_MOSI, SPI_SCK, OLED_DC, OLED_RST, SPI_CS_PIN_OLED);
Adafruit_SSD1306 display(SCREEN_WIDTH, SCREEN_HEIGHT, &SPI, OLED_DC, OLED_RST, SPI_CS_PIN_OLED, OLED_SPI_BAUD);

MCP_CAN CAN0(SPI_CS_PIN_CAN);

unsigned char last_rendered_id = 255;
bool use_imperial = false;
unsigned char slot_map[8] = {0, 1, 3, 2, 5, 3, 4, 3};

struct {
  unsigned char id; // increments each time this is changed
  unsigned char temperature; // 0 for off, or 1+
  unsigned long last_pa; // time of last park assist notification
  unsigned char park_assist_slot; // 0 through 5
  unsigned char park_assist_level; // 0 or 1-4
  unsigned char park_assist_distance; // in cm
} data_state;

void getTextBounds(const char *str, GFXfont *font, int *width, int *height) {
  uint16_t x, y, x1, y1;
  display.setTextSize(1);
  display.setFont(font);
  display.getTextBounds(str, &x, &y, &x1, &y1, width, height);
}

void calculateTemperature(int* result) {
  *result = ((int)data_state.temperature / 2) - 40;

  if (use_imperial) {
    *result = round((1.8 * (float)*result) + 32.0);
  }
}

void calculateImperialDistance(unsigned char *feet, unsigned char *inches) {
  float inches_f = 0.393701 * data_state.park_assist_distance;
  *feet = inches_f / 12;
  *inches = inches_f - (*feet * 12);
}

void renderTemperature() {
  display.clearDisplay();

  char text[10];
  char unit = use_imperial ? 'F' : 'C';
  int temperature, width, height;

  calculateTemperature(&temperature);
  sprintf(text, "%d  %c", temperature, unit);

  getTextBounds(text, &FreeSans18pt7b, &width, &height);

  display.setTextSize(1);
  display.setTextColor(SSD1306_WHITE);
  display.setFont(&FreeSans18pt7b);

  display.setCursor((SCREEN_WIDTH - width) / 2, (SCREEN_HEIGHT + height) / 2);
  display.write(text);
  Serial.println(text);
  Serial.println((SCREEN_WIDTH - width) / 2);
  Serial.println((SCREEN_HEIGHT + height) / 2);

  int degOffsetX = ((SCREEN_WIDTH + width) / 2) - 25;
  display.drawCircle(degOffsetX, 8, 3, SSD1306_WHITE);
  display.drawCircle(degOffsetX, 8, 4, SSD1306_WHITE);

  display.display();
}

void calculateParkAssistLevelAndSlot(unsigned char buf[8], unsigned char *slot, unsigned char *level) {
  unsigned char tmpLevel = 255;
  unsigned char tmpSlot = 0;

  // MR, 0L
  for (size_t index = 0; index < 2; index++) {
    unsigned char a = (buf[3 - index] & 0x0F) - 1; //L,R
    unsigned char b = ((buf[3 - index] & 0xF0) >> 4) - 1; //0,M

    if (a < 255) {
      tmpSlot |= (1 << (index * 2));
    }

    if (b < 255) {
      tmpSlot |= (1 << ((index * 2) + 1));
    }

    if (a <= b && tmpLevel > a) {
      tmpLevel = a;
    } else if (b <= a && tmpLevel > b) {
      tmpLevel = b;
    }
  }

  *slot = tmpSlot > 7 ? slot_map[7] : slot_map[tmpSlot];
  *level = tmpLevel + 1;
}

bool shouldShowRect() {
  unsigned long now = millis();
  // use level - 4 = slow, 1 = fast
  switch (data_state.park_assist_level) {
    case 4:
      return now % 1000 < 500;
    case 3:
      return now % 650 < 325;
    case 2:
      return now % 300 < 150;
    case 1:
      return true;
    default:
      return false;
  }
}

void renderParkAssistRect() {
  display.fillRect(0, SCREEN_HEIGHT - PA_BAR_H, SCREEN_WIDTH, PA_BAR_H, SSD1306_BLACK);

  if (shouldShowRect()) {
    display.fillRect(PA_BAR_MARGIN + ((data_state.park_assist_slot - 1) * PA_BAR_W), SCREEN_HEIGHT - PA_BAR_H, PA_BAR_W + PA_BAR_EXTRA_W, PA_BAR_H, SSD1306_WHITE);
  }
}

void renderParkAssist() {
  display.clearDisplay();

  char text[12];
  unsigned char feet, inches;
  int width, height;
  calculateImperialDistance(&feet, &inches);

  if (use_imperial) {
    calculateImperialDistance(&feet, &inches);

    if (feet > 0) {
      sprintf(text, "%dft %din", feet, inches);
    } else {
      sprintf(text, "%din", inches);
    }
  } else {
    sprintf(text, "%dcm", data_state.park_assist_distance);
  }

  display.setTextSize(1);
  display.setTextColor(SSD1306_WHITE);
  display.setFont(&FreeSans9pt7b);

  // distance measurement
  getTextBounds(text, &FreeSans9pt7b, &width, &height);
  display.setCursor((SCREEN_WIDTH - width) / 2, height);
  display.write(text);

  renderParkAssistRect();
  display.display();
}

void setup() {
  Serial.begin(SER_BAUD);
  Serial.println("Hello!");

  pinMode(UNIT_SW, INPUT);
  pinMode(PGOOD_3V3, INPUT);

  use_imperial = !digitalRead(UNIT_SW);

  if (use_imperial) {
    Serial.println("Imperial units selected");
  } else {
    Serial.println("Metric units selected");
  }

  while (CAN_OK != CAN0.begin(MCP_STDEXT, CAN_33K3BPS, MCPHZ)) {
    Serial.println("Waiting for CANBUS bootup");
    delay(500);
  }

  Serial.println("Setting CANBUS filters");

  CAN0.init_Mask(0, 1, 0x00FFE000);
  CAN0.init_Filt(0, 1, 0x00424000);
  CAN0.init_Filt(1, 1, 0x003A8000);
  CAN0.init_Mask(1, 0, 0x00FF0000);
  CAN0.init_Filt(2, 0, 0x00000000);
  CAN0.init_Filt(3, 0, 0x00000000);
  CAN0.init_Filt(4, 0, 0x00000000);
  CAN0.init_Filt(5, 0, 0x00000000);
  // delay(100);
  CAN0.setMode(MCP_LISTENONLY);
  pinMode(CAN0_INT, INPUT);

  Serial.println("CANBUS bootup complete");

  // wait until PGOOD_3V3 is OK, then wait additional 250ms before trying OLED
  while (!digitalRead(PGOOD_3V3)) {
    Serial.println("Waiting for 3.3V PGOOD signal");
    delay(250);
  }

  delay(250);
  Serial.println("Confirmed 3.3V PGOOD signal");
  
  while (!display.begin(SSD1306_SWITCHCAPVCC)) {
    Serial.println("Waiting for OLED bootup");
    delay(500);
  }

  display.clearDisplay();
  display.display();
  Serial.println("OLED bootup complete");

  Serial.println("Go!");
}

void loop() {
  unsigned long now = millis();

  unsigned long canId, arbId;
  unsigned char len;
  unsigned char buf[8];

  if (!digitalRead(CAN0_INT)) {
    CAN0.readMsgBuf(&canId, &len, buf);
    arbId = GMLAN_ARB(canId);

    if (arbId == 0x1D4) { // 0x103A80BB or 0x??3A8???
      // rear park assist sonar
      unsigned char PA_STATUS = (buf[0] & 0x0F);
      if (PA_STATUS == 0x00) {
        Serial.println("PA ON");
        Serial.println(buf[1]);
        // PA ON
        // buf[1] is shortest real distance to closest object, from 0x00 to 0xFF, in centimeters (multiply by 0.0328084 for feet!)
        // buf[2~3] nibbles are [M, R, 0, L]
        // expect car to display single value in L, L+M, M, M+R, R - but take lowest nonzero
        // intent is to show distance in one of five positions on screen
        // 0 = nothing, 1 = stop (red/solid), 2 = close (red/blinking fast), 3 = medium (yellow/blinking medium), 4 = far (yellow/blinking slow)

        data_state.last_pa = now | 1; // never 0, buf 1 millis off is OK
        data_state.park_assist_distance = buf[1];
        calculateParkAssistLevelAndSlot(buf, &data_state.park_assist_slot, &data_state.park_assist_level);
        data_state.id++; // always increment because last_pa is different
      } else if (PA_STATUS == 0x0F) {
        Serial.println("PA OFF");
        // PA OFF
        data_state.last_pa = 0;
        data_state.park_assist_distance = 0;
        data_state.park_assist_level = 0;
        data_state.park_assist_slot = 0;
        data_state.id++;
      } else {
        Serial.println("PA UNK");
        Serial.println(PA_STATUS);
      }
    } else if (arbId == 0x212) { // 0x10424060 or 0x??424???
      Serial.println("TEMP");
      Serial.println(buf[1]);
      if (data_state.temperature != buf[1]) {
        data_state.temperature = buf[1];
        data_state.id++;
      }
    }
  }

  if (data_state.last_pa && data_state.last_pa + PA_TIMEOUT < now) {
    Serial.println("Last PA too old");
    data_state.last_pa = 0;
    data_state.park_assist_distance = 0;
    data_state.park_assist_level = 0;
    data_state.park_assist_slot = 0;
    data_state.id++;
  }

  if (last_rendered_id != data_state.id) {
    last_rendered_id = data_state.id;
    if (data_state.last_pa) {
      Serial.println("Render PA");
      renderParkAssist();
    } else if (data_state.temperature) {
      Serial.println("Render TEMP");
      renderTemperature();
    } else {
      Serial.println("Clear");
      display.clearDisplay();
      display.display();
    }
  } else if (data_state.last_pa) { // if active PA
    Serial.println("Render PA Rect");
    renderParkAssistRect();
    display.display();
  }
}

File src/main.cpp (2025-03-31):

#include <Arduino.h>
#include "DataTypes.h" // include before others, especially mcp_can, to normalize data types
#include <SPI.h>
#include <mcp_can.h>
#include <Adafruit_GFX.h>
#include <Adafruit_SSD1306.h>

#include "OLED.h"
#include "GMLan.h"
#include "Flash.h"
#include "Renderer.h"
#include "GMTemperature.h"
#include "GMParkAssist.h"
#include "Watchdog.h"
#include "Debug.h"

// communications
constexpr auto SER_BAUD = 115200UL;
constexpr auto OLED_SPI_BAUD = 1000000UL;

#if F_CPU == 200000000
constexpr uint8_t MCP_HZ = MCP_20HZ;
#elif F_CPU == 16000000
constexpr uint8_t MCP_HZ = MCP_16MHZ;
#elif F_CPU == 8000000
constexpr uint8_t MCP_HZ = MCP_8MHZ;
#else
constexpr uint8_t MCP_HZ = ERROR_BAD_F_CPU;
#endif

// pin definitions: CANBUS
constexpr uint8_t SPI_CS_PIN_CAN = 7;
constexpr uint8_t CAN_INT = 16;

// pin definitions: OLED display
constexpr uint8_t SPI_CS_PIN_OLED = 2;
constexpr uint8_t OLED_DC = 4;
constexpr uint8_t OLED_RST = 3;

// pin definitions: SPI
constexpr uint8_t SPI_MOSI = 11;
constexpr uint8_t SPI_MISO = 12;
constexpr uint8_t SPI_SCK = 13;

// CANBUS filter data
struct CanMaskFilterData {
    uint8_t ext = 0;
    uint32_t ulData = 0x00000000;
};

constexpr CanMaskFilterData masks[2] = {
    {1, 0x00FFE000},
    {1, 0x00FFE000},
};

constexpr CanMaskFilterData filters[6] = {
    {1, GMLAN_R_ARB(GMLAN_MSG_TEMPERATURE)},
    {1, GMLAN_R_ARB(GMLAN_MSG_PARK_ASSIST)},
    {1, GMLAN_R_ARB(GMLAN_MSG_CLUSTER_UNITS)},
    {1, 0x00000000},
    {1, 0x00000000},
    {1, 0x00000000},
};

/**
 * Run initialization function, and evaluate its result
 * If enough errors happen, the MCUs on the board all get rebooted by the reset supervisor
 * @tparam Delegate type of delegateFn lambda function
 * @tparam Result type of return value of delegateFn lambda function and of expectedValue arg
 * @tparam OnError type of onErrorFn lambda function
 * @param watchdog the watchdog instance
 * @param delegateFn the lambda function to run
 * @param expectedValue the expected (successful) result
 * @param onErrorFn lambda function run on error, usually logging / delay logic
 */
template<typename Delegate, typename Result, typename OnError>
void runWithWatchdog(Watchdog* watchdog, Delegate delegateFn, Result expectedValue, OnError onErrorFn) {
    Result result = expectedValue;

    // loop will eventually exit, once watchdog errors hit limit, it will reboot the device
    do {
        result = delegateFn();

        if (result != expectedValue) {
            onErrorFn(result);
            watchdog->countError();
        }
    } while (result != expectedValue);
}

/**
 * CANBUS initialization
 * Starts in listen-only mode, with filters for useful ARB IDs
 * Without the filters, app would have to process many more messages than necessary
 * @param canBus
 * @param watchdog
 */
void initializeCanBus(MCP_CAN* canBus, Watchdog* watchdog) {
    DEBUG(Serial.println(F("Initializing MCP25625")));

    runWithWatchdog(
        watchdog,
        [canBus] {
            return canBus->begin(MCP_STDEXT, CAN_33K3BPS, MCP_HZ);
        },
        static_cast<uint8_t>(CAN_OK),
        [](const uint8_t errorCode) {
            DEBUG(Serial.printf(F("MCP25625 initialization failed, error code =%u\n"), errorCode));
            delay(500);
        }
    );

    DEBUG(Serial.println(F("Setting MCP25625 masks and filters")));

    for (uint8_t maskId = 0; maskId < 2; maskId++) {
        auto mask = masks[maskId];

        runWithWatchdog(
            watchdog,
            [canBus, maskId, mask] {
                DEBUG(Serial.printf(F("MCP25625 Set mask num=%u ext=%u ulData=0x%08lx\n"), maskId, mask.ext, mask.ulData));
                return canBus->init_Mask(maskId, mask.ext, mask.ulData);
            },
            static_cast<uint8_t>(CAN_OK),
            [maskId](const uint8_t errorCode) {
                DEBUG(Serial.printf(F("MCP25625 setting mask %u failed, error code =%u\n"), maskId, errorCode));
                delay(500);
            }
        );

        const uint8_t filterStart = maskId == 0 ? 0 : 2;
        const uint8_t filterEnd = maskId == 0 ? 2 : 6;

        for (uint8_t filterId = filterStart; filterId < filterEnd; filterId++) {
            auto filter = filters[filterId];

            runWithWatchdog(
                watchdog,
                [canBus, filterId, filter] {
                    DEBUG(Serial.printf(F("MCP25625 Set filter num=%u ext=%u ulData=0x%08lx\n"), filterId, filter.ext, filter.ulData));
                    return canBus->init_Filt(filterId, filter.ext, filter.ulData);
                },
                static_cast<uint8_t>(CAN_OK),
                [filterId](const uint8_t errorCode) {
                    DEBUG(Serial.printf(F("MCP25625 setting filter %u failed, error code =%u\n"), filterId, errorCode));
                    delay(500);
                }
            );
        }
    }

    DEBUG(Serial.println(F("Setting MCP25625 mode to listen")));

    runWithWatchdog(
        watchdog,
        [canBus] {
            return canBus->setMode(MCP_LISTENONLY);
        },
        static_cast<uint8_t>(CAN_OK),
        [](const uint8_t errorCode) {
            DEBUG(Serial.printf(F("MCP25625 could not enter listen-only mode, error code =%u\n"), errorCode));
            delay(500);
        }
    );

    pinMode(CAN_INT, INPUT); // set up interrupt

    DEBUG(Serial.println(F("MCP25625 initialization complete")));
}

/**
 * OLED display setup
 * Will also blank out the display
 * @param display
 * @param watchdog
 */
void initializeOledDisplay(Adafruit_SSD1306* display, Watchdog* watchdog) {
    DEBUG(Serial.println(F("Initializing SSD1306 OLED")));

    runWithWatchdog(
        watchdog,
        [display] {
            return display->begin(SSD1306_SWITCHCAPVCC);
        },
        true,
        [](const bool errorCode) {
            DEBUG(Serial.printf(F("SSD1306 OLED initialization error %u\n"), errorCode));
        }
    );

    display->clearDisplay();
    display->display();
    DEBUG(Serial.println(F("SSD1306 OLED initialization complete")));
}
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

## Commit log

2024-07-21 Add 3.3V PGOOD trace
    [car-display-v5.kicad_pcb, car-display-v5.kicad_sch]
2024-08-03 Modify 3.3V trace
    [car-display-v5.kicad_pcb]
2024-08-03 Move OLED connector to side opposite of CAN input
    [car-display-v5.kicad_pcb, car-display-v5.kicad_sch]
2025-01-30 Work on V6 pCB
    [car-display-v6.kicad_pcb, car-display-v6.kicad_sch]
2025-03-06 Work on V6 code for PlatformIO
    [car-display-v6.kicad_pcb, car-display-v6.kicad_sch]
2025-03-07 Fix iterators and update based on feedback from car
    [GMParkAssist.cpp, main.cpp]
2025-03-08 Fix PSU error
    [car-display-v6.kicad_pcb, car-display-v6.kicad_sch]
2025-03-12 Add detection for selected measurement units via canbus
2025-03-12 Update PCB with new power supply and return to MCP25625
    [car-display-v6.kicad_pcb, car-display-v6.kicad_sch]
2025-03-12 Rearrange repository
    [atmega328pb-dip.kicad_pcb, atmega328pb-dip.kicad_sch, car-display-v3.kicad_pcb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]
2025-03-12 Update PCB connectors
    [car-display-v6.kicad_pcb, car-display-v6.kicad_sch]
2025-03-12 Move some pins around
    [car-display-v6.kicad_pcb, car-display-v6.kicad_sch]
2025-03-12 PCB updates
    [car-display-v6.kicad_pcb]
2025-03-23 Fix issue in park assist
    [GMParkAssist.cpp]
2025-03-30 Production cleanup
    [car-display-v6.kicad_sch]
2025-03-31 Switch to regular array for renderers
2025-03-31 PCB guides
    [car-display-v6.kicad_pcb]
